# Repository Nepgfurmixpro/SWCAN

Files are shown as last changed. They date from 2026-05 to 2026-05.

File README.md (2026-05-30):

# SWCAN Reader
This project defines a schematic and pcb of a small single board SWCAN reader using USB CDC for computer communication and a TH8056 as the transciever, utilizing a STM32 MCU as the boards brain. The board includes a SWD header to allow for initial programming, future programming possible through DFU using the bootloader.

This board is in development and may see changes.

### Software Used
* KiCAD 10
* STM32CubeMX
* STM32CubeProgrammer
* CLion
* CMake

The STM32 MCU is a STM32G491KCU6

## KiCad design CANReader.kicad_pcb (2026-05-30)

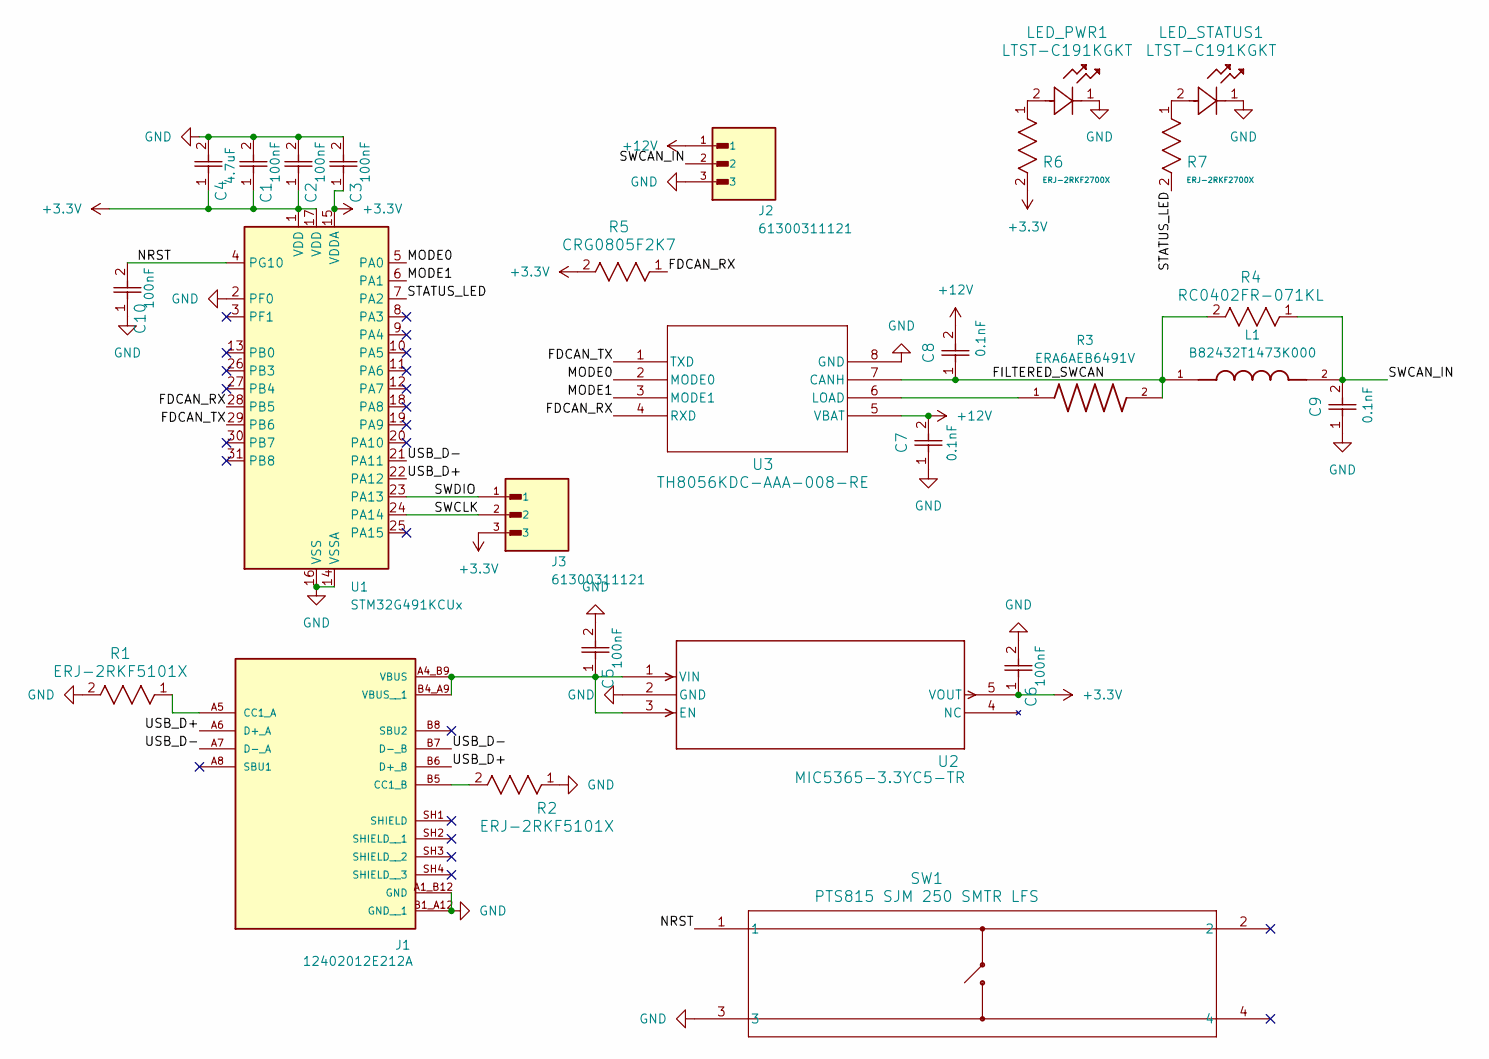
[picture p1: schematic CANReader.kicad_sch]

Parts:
C1, C2, C3, C5, C6, C10: CL05B104KP5NNNC; CAP_CL05_SAM-L
C4: CL05A475MP5NRNC; CAP_CL05_SAM
C7, C8, C9: CL05C101JB5NNNC; CAP_CL05_SAM
J1: 12402012E212A; AMPHENOL_12402012E212A; PARTREV 4
J2, J3: 61300311121; WURTH_61300311121; PARTREV 003.001
L1: B82432T1473K000; INDM4532X340N; PARTREV N/A
LED_PWR1: LTST-C191KGKT; LED_LTST-C191KGKT_LTO-L
LED_STATUS1: LTST-C191KGKT; LED_LTST-C191KGKT_LTO-L
R1, R2: ERJ-2RKF5101X; RC0402N_PAN-L
R3: ERA6AEB6491V; RES_ERA6AEB6491V; PARTREV 3/1/2020
R4: RC0402FR-071KL; RC0402N_YAG-L
R5: CRG0805F2K7; RES0805_CRG_TYCO_TYC-L
R6, R7: ERJ-2RKF2700X; RC0402N_PAN
SW1: PTS815 SJM 250 SMTR LFS; SW4_PTS815_SJM_250_SMTR_LFS_CNK
U1: STM32G491KCUx; QFN-32-1EP_5x5mm_P0.5mm_EP3.45x3.45mm_ThermalVias
U2: MIC5365-3.3YC5-TR; SC-70_C5_MCH-L
U3: TH8056KDC-AAA-008-RE; MEL_SOIC-8_MEL-L

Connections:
+3.3V: C1.1, C2.1, C3.1, C4.1, C6.1, J3.3, R5.2, R6.2, U1.1 (VDD), U1.15 (VDDA), U1.17 (VDD), U2.5 (VOUT)
+12V: C7.2, C8.2, J2.1, U3.5 (VBAT)
/FDCAN_RX: R5.1, U1.28 (PB5), U3.4 (RXD)
/FDCAN_TX: U1.29 (PB6), U3.1 (TXD)
/FILTERED_SWCAN: C8.1, L1.1, R3.2, R4.2, U3.7 (CANH)
/MODE0: U1.5 (PA0), U3.2 (MODE0)
/MODE1: U1.6 (PA1), U3.3 (MODE1)
/NRST: C10.2, SW1.1, U1.4 (PG10)
/STATUS_LED: R7.2, U1.7 (PA2)
/SWCAN_IN: C9.2, J2.2, L1.2, R4.1
/SWCLK: J3.2, U1.24 (PA14)
/SWDIO: J3.1, U1.23 (PA13)
/USB_D+: J1.A6 (D+_A), J1.B6 (D+_B), U1.22 (PA12)
/USB_D-: J1.A7 (D-_A), J1.B7 (D-_B), U1.21 (PA11)
GND: C1.2, C2.2, C3.2, C4.2, C5.2, C6.2, C7.1, C9.1, C10.1, J1.A1_B12 (GND), J1.B1_A12 (GND__1), J2.3, LED_PWR1.1, LED_STATUS1.1, R1.2, R2.1, SW1.3, U1.2 (PF0), U1.14 (VSSA), U1.16 (VSS), U1.32 (VSS), U1.33 (VSS), U2.2 (GND), U3.8 (GND)
unnamed: J1.A5 (CC1_A), R1.1
unnamed: J1.B5 (CC1_B), R2.2
unnamed: C5.1, J1.A4_B9 (VBUS), J1.B4_A9 (VBUS__1), U2.1 (VIN), U2.3 (EN)
unnamed: LED_PWR1.2, R6.1
unnamed: LED_STATUS1.2, R7.1
unnamed: R3.1, U3.6 (LOAD)

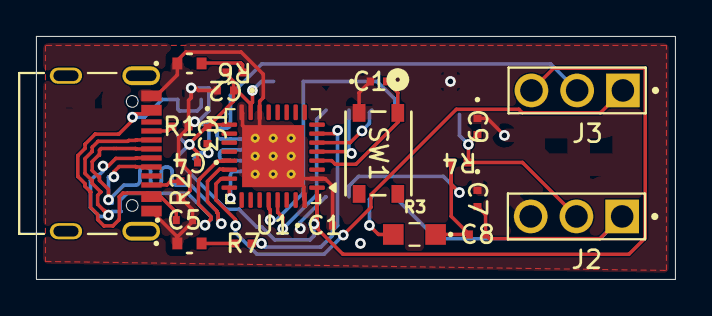
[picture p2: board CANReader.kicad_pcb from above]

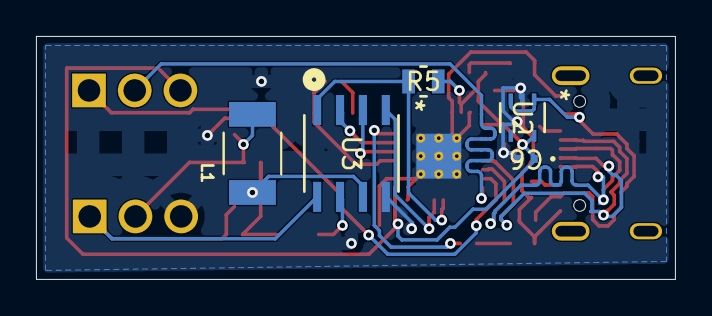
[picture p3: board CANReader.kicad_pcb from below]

Board: 2 copper layers, 35.5 x 13.5 mm, 27 parts (5 on the bottom side), 21 nets.

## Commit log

2026-05-30 Remove built .zip gerber files
2026-05-30 Add bom to gitignore
